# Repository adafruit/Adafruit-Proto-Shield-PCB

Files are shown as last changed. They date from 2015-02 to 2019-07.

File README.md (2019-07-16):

## Adafruit Proto Shield for Arduino Unassembled Kit - Stackable - Version R3 PCB

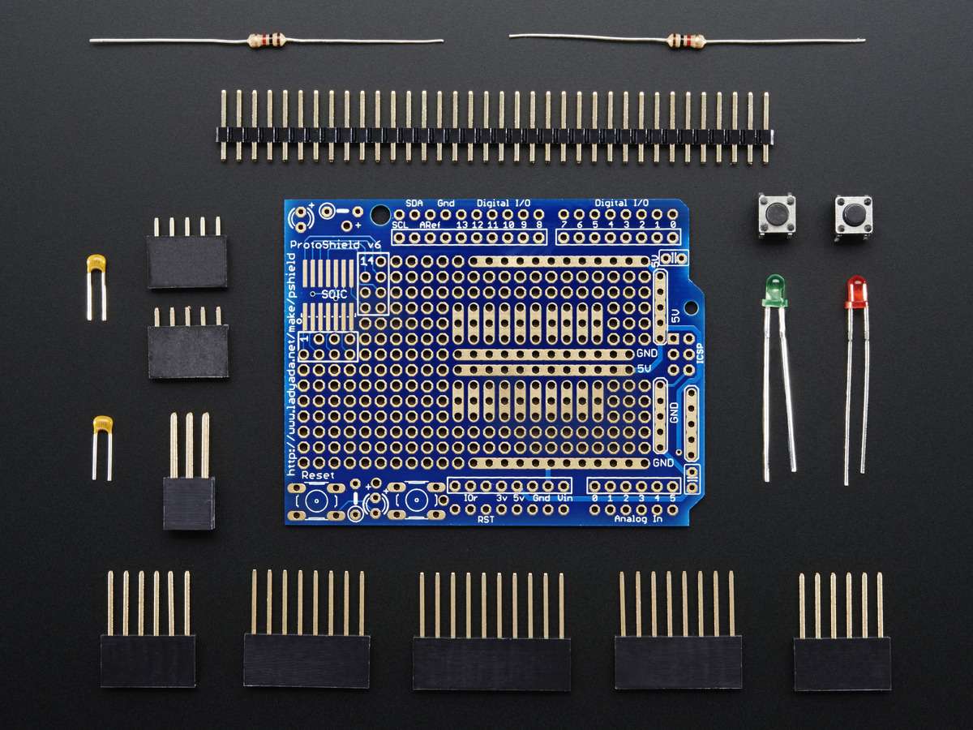
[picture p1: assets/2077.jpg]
<a href="http://www.adafruit.com/products/2077"><br/>
Click here to purchase one from the Adafruit shop</a>

PCB files for the Adafruit Proto Shield for Arduino Unassembled Kit - Stackable - Version R3. Format is EagleCAD schematic and board layout
* https://www.adafruit.com/product/2077

### Description

This prototyping shield is the best out there (well, we think so, at least), and now is even better with **Version R3** - updated for the most compatibility with just about all the Arduinos! It works with UNO, Mega, Leonardo, NG, Diecimila, Duemilanove, and compatible Arduinos. Yun's and Arduino Ethernets have a chunky Ethernet jack that gets in the way of stacking, you can use the stacking headers included and it will work, just doesn't sit nice and flat.

Check out these awesome specifications:

 * It has a nice standard 0.1"x0.1" prototying grid with big pads
 * Comes with Stacking headers and plain header, choose whichever you want when soldering together
 * A IC pattern for adding DIP ICs up to 20 pins
 * Power rails down the middle and sides
 * A reset button and an extra general use button
 * 2 3mm general use LEDs, red and green, as well as 2 matching resistors
 * A pass-thru ICSP stacking header so you can stack any kind of shield on top, and/or use an AVR programmer
 * A surface-mount chip area for up to 14 SOIC size parts
 * Compatible with tiny breadboards
 * Every pin is brought out!
 * Gold plated pads
 * 2 x 0.1uF capacitors on either side for extra power stability
**Comes as a kit of parts** so you can choose how you want to configure your shield. However its very easy to assemble even for beginning solderers. [More information & instructions are available here](http://learn.adafruit.com/adafruit-proto-shield-arduino).

**Arduino and breadboards are not included!**

### License

Adafruit invests time and resources providing this open source design, please support Adafruit and open-source hardware by purchasing products from [Adafruit](https://www.adafruit.com)!

Designed by Limor Fried/Ladyada for Adafruit Industries.

Creative Commons Attribution/Share-Alike, all text above must be included in any redistribution. See license.txt for additional details.

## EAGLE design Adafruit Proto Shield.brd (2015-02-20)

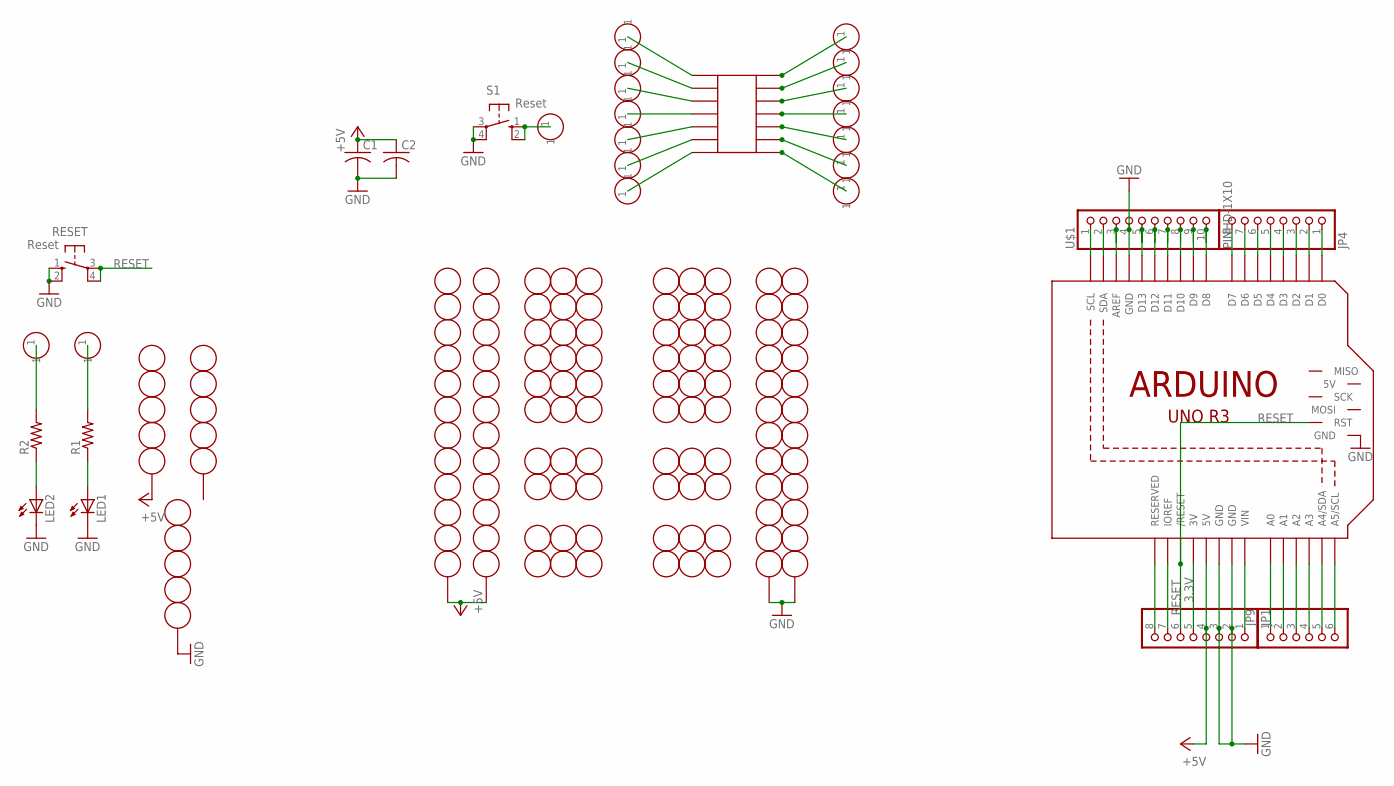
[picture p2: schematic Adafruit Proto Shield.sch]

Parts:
C1, C2: C-US025-025X050; C025-025X050
GNDSTRIP1, GNDSTRIP2: 12-STRIP
IC1: SMD-14; SO-14NMW
JP1, JP4: PINHD-1X8BIG; 1X08-BIG
JP9: PINHD-1X6B; 1X06-BIG
LED1, LED2: LED3MM
M1: ARDUINO_R3_ICSP; ARDUINOR3_ICSP
R1, R2: R-US_0207/5V; 0207/5V
RESET: Reset; B3F-10XX
S1: Reset; B3F-10XX
U$1: PINHD-1X10; 1X10-BIG
U$2, U$4, U$6, U$7, U$8, U$9, U$16, U$19, U$25, U$27, U$34, U$35, U$37, U$38, U$39, U$40, U$41: PERFHOLE
U$3, U$24, U$43: 5-STRIP
U$5, U$10, U$11, U$12, U$13, U$14, U$15, U$17, U$18, U$20, U$21, U$22, U$23, U$26, U$28, U$29, U$30, U$31, U$32, U$33: 3-STRIP
VCCSTRIP1, VCCSTRIP2: 12-STRIP

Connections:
3.3V: JP1.5, M1.3V
+5V: C1.1, C2.1, JP1.4, M1.5V, U$24.P$3, VCCSTRIP1.P$1, VCCSTRIP2.P$1
GND: C1.2, C2.2, GNDSTRIP1.P$1, GNDSTRIP2.P$1, JP1.2, JP1.3, LED1.K (C), LED2.K (C), M1.GND, M1.GND@1 (GND), M1.GND@2 (GND), M1.GND@3 (GND), RESET.1 (S), RESET.2 (S1), S1.3, S1.4 (P1), U$1.4, U$43.P$3
unnamed: M1.AREF, U$1.3
unnamed: JP1.8, M1.RESERVED
unnamed: M1.D13, U$1.5
unnamed: LED1.A, R1.1
unnamed: JP1.7, M1.IOREF
unnamed: R1.2, U$7.1
unnamed: R2.2, U$4.1
unnamed: LED2.A, R2.1
unnamed: M1.D12, U$1.6
unnamed: M1.D11, U$1.7
unnamed: M1.D10, U$1.8
unnamed: M1.D9, U$1.9
unnamed: M1.D8, U$1.10
unnamed: JP9.1, M1.A0
unnamed: JP9.2, M1.A1
unnamed: JP9.3, M1.A2
unnamed: JP9.4, M1.A3
unnamed: JP9.5, M1.A4 (A4/SDA)
unnamed: JP9.6, M1.A5 (A5/SCL)
unnamed: JP4.1, M1.D0
unnamed: JP4.2, M1.D1
unnamed: JP4.3, M1.D2
unnamed: JP4.4, M1.D3
unnamed: JP4.5, M1.D4
unnamed: IC1.P$1, U$2.1
unnamed: IC1.P$2, U$6.1
unnamed: JP4.6, M1.D5
unnamed: JP4.7, M1.D6
unnamed: IC1.P$3, U$8.1
unnamed: IC1.P$4, U$9.1
unnamed: IC1.P$5, U$19.1
unnamed: JP4.8, M1.D7
unnamed: JP1.1, M1.VIN
unnamed: M1.SCL, U$1.1
unnamed: IC1.P$6, U$25.1
unnamed: IC1.P$7, U$27.1
unnamed: IC1.P$8, U$34.1
unnamed: IC1.P$9, U$35.1
unnamed: IC1.P$10, U$37.1
unnamed: M1.SDA, U$1.2
unnamed: IC1.P$11, U$38.1
unnamed: IC1.P$12, U$39.1
unnamed: IC1.P$13, U$40.1
unnamed: IC1.P$14, U$41.1
unnamed: S1.1 (S), S1.2 (S1), U$16.1
RESET: JP1.6, M1.RESET (/RESET), M1.RESET_ICSP (RST), RESET.3, RESET.4 (P1)

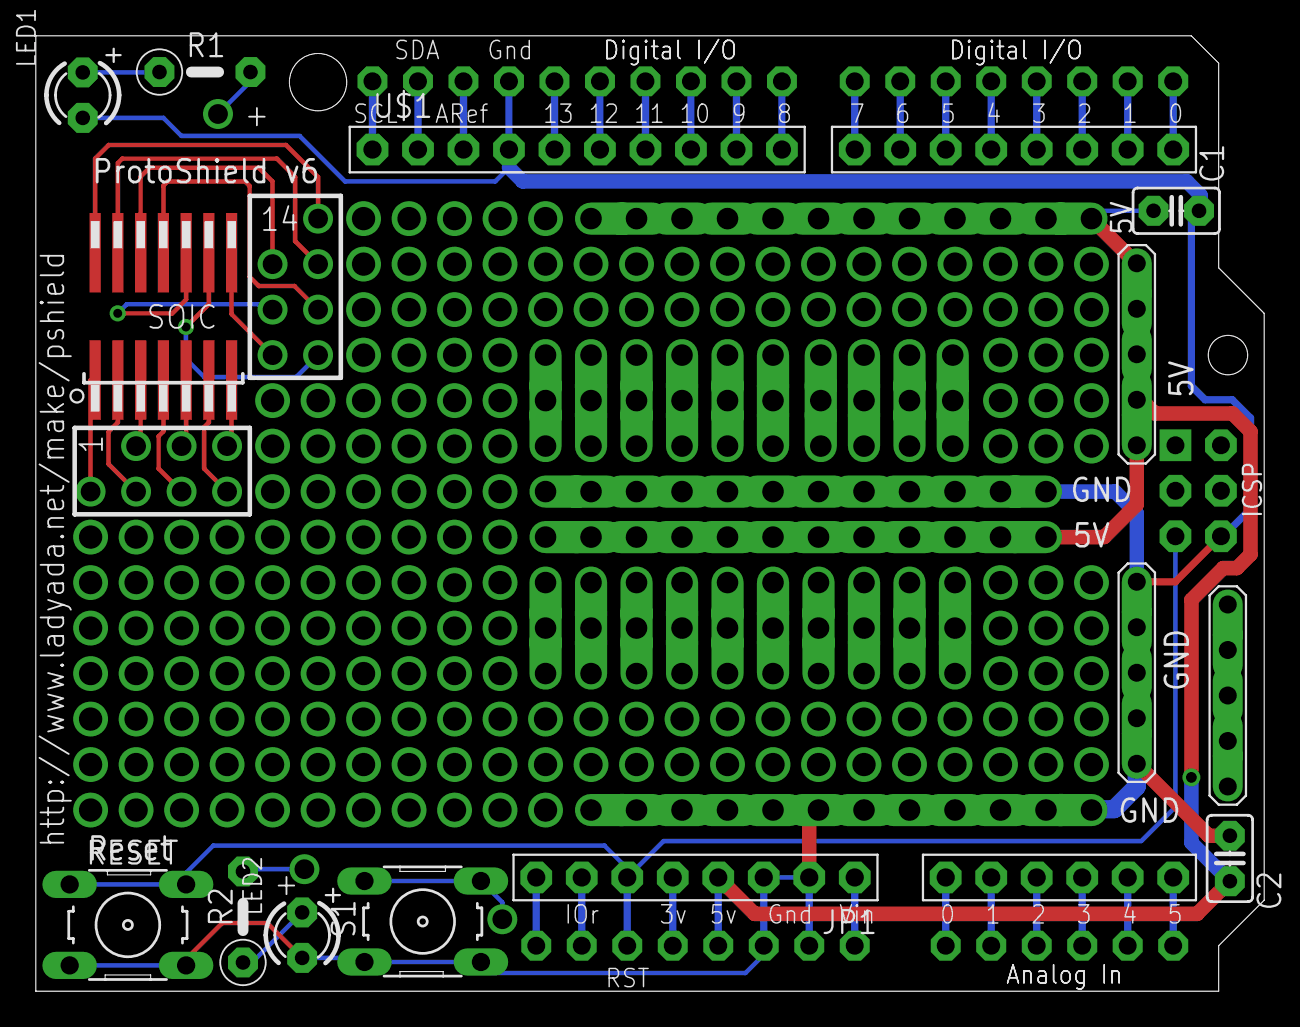
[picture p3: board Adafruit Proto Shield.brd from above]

Board: 2 copper layers, 68.6 x 53.3 mm, 59 parts (1 on the bottom side), 49 nets.

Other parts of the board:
U$36: ADAFRUIT_9MM

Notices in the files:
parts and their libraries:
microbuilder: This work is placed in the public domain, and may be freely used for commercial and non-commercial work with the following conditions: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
